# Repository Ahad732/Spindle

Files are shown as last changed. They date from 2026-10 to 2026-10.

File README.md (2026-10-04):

# Spindle

Spindle is a low-cost, custom e-reader made with the RP2350A. It consists of a 2.7 inch e-paper display, which is much better than a typical screen. It also consists of a 128Mbit flash, which is 16MiB, and 5 user buttons. The firmware for Spindle can be found [here](https://github.com/Keyaan-07/spindle-firmware/tree/main). The firmware is custom written in C. The power consumption averages at about 40mA, making it a low-power device.  

See the board on [KiCanvas](https://kicanvas.org/?repo=https%3A%2F%2Fgithub.com%2FAhad732%2FSpindle%2Ftree%2Fmain%2FHardware)  

## Features:
- Dual ARM-Cortex M-33 and Hazard3 RISC-V cores
- WiFi Functionality
- 16MiB flash
- 2.7 inch e-paper display
- 100% open-sourced
- USB High Speed compatible
- switching charging
- low-power consumption

# CAD: 
So, the CAD is made in onshape, [link here](https://cad.onshape.com/documents/20ea073a3a4d1e1a3f911dd9/w/66e638eb5b2ab30e1451aaff/e/b663f709698147c3db960dcd). We have tried our best to make it look as clean as possible.  This is what the assembly looks like:  
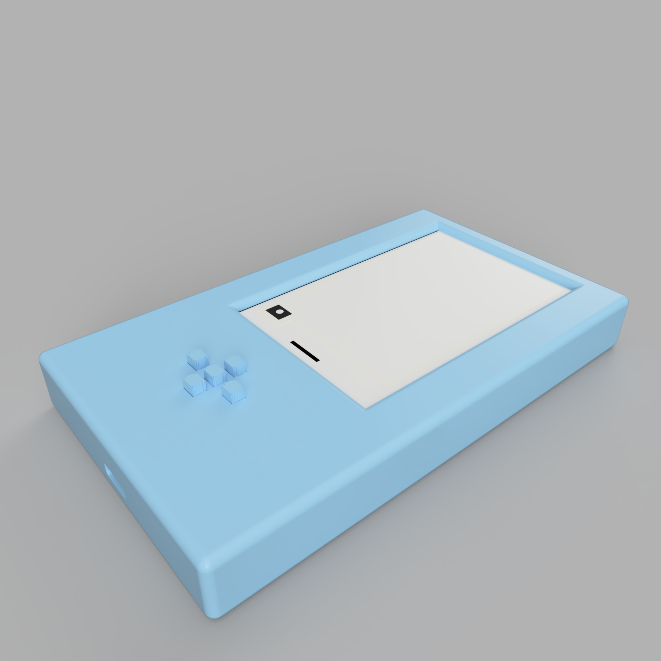
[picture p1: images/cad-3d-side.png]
cad-3d
  
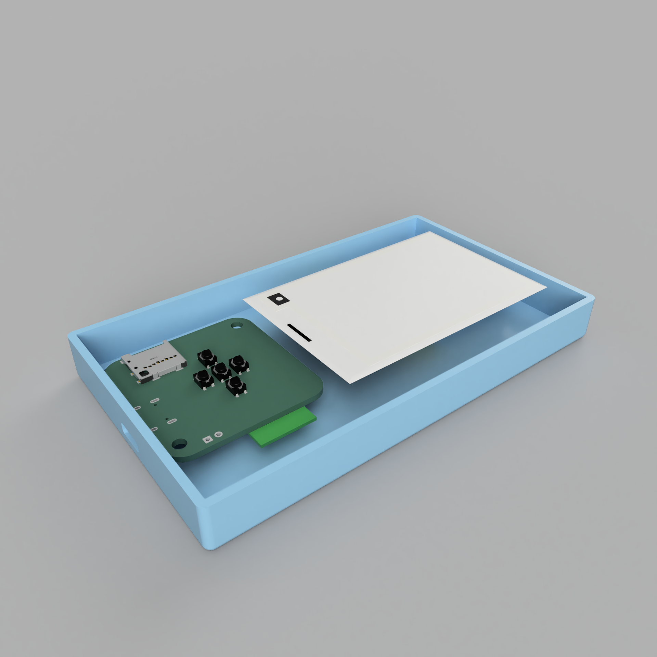
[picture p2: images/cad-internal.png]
cad-internal
  

## Images:  
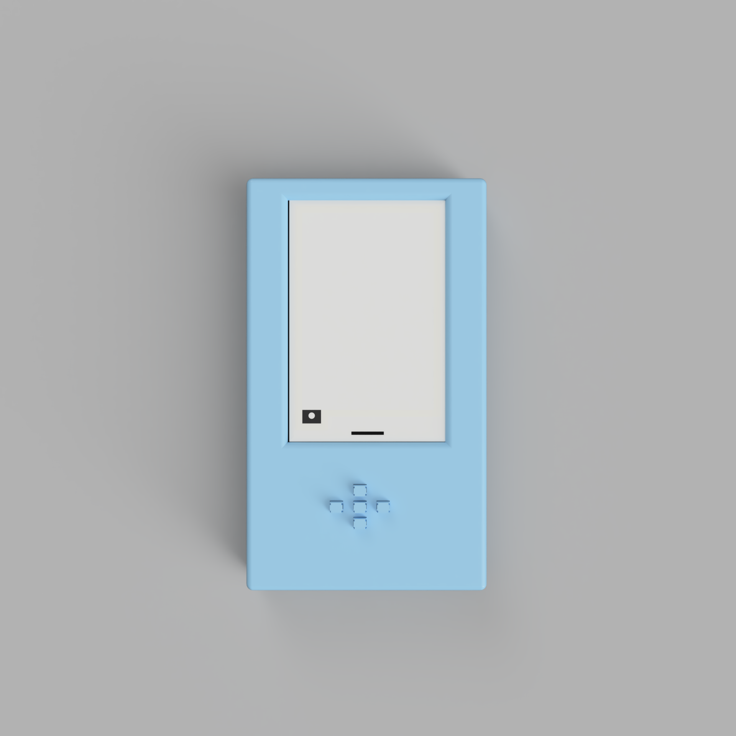
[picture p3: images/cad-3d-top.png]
3d-render

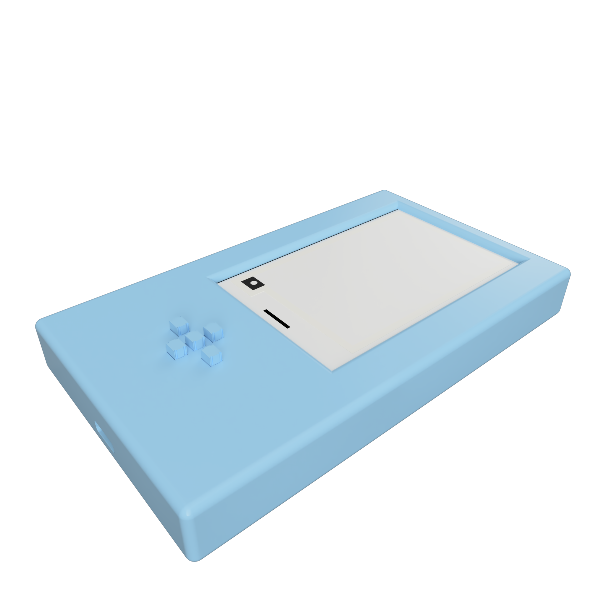
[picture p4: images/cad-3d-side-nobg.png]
3d-side
  
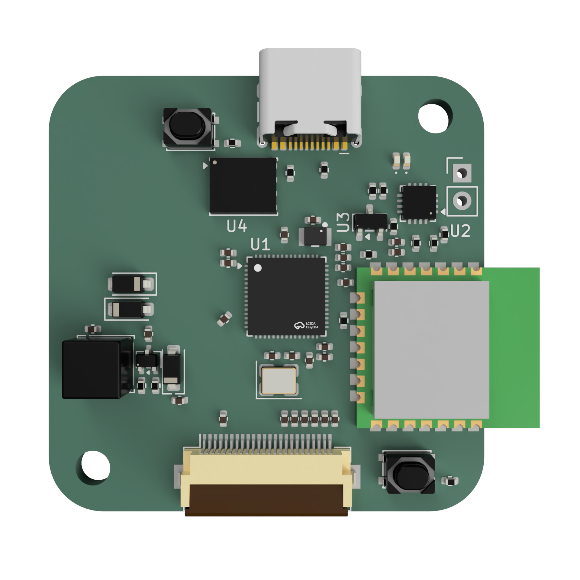
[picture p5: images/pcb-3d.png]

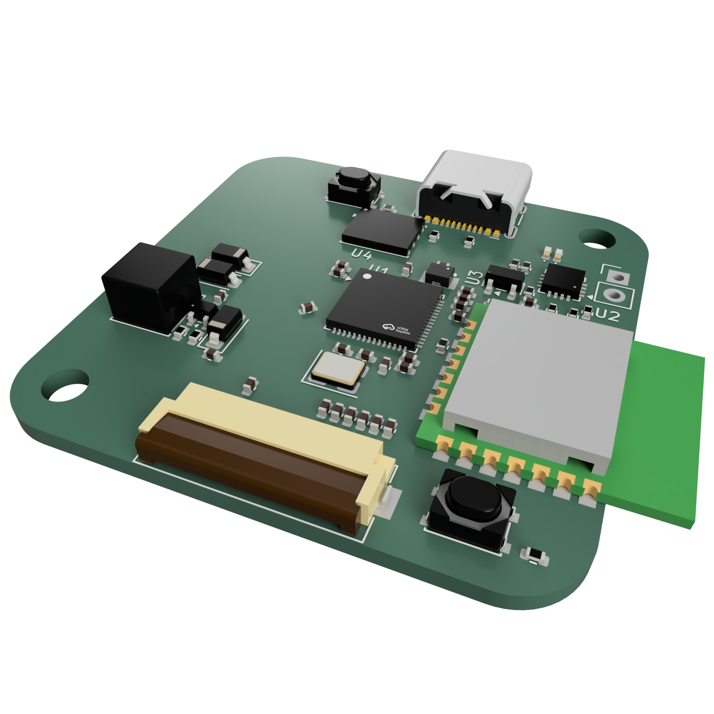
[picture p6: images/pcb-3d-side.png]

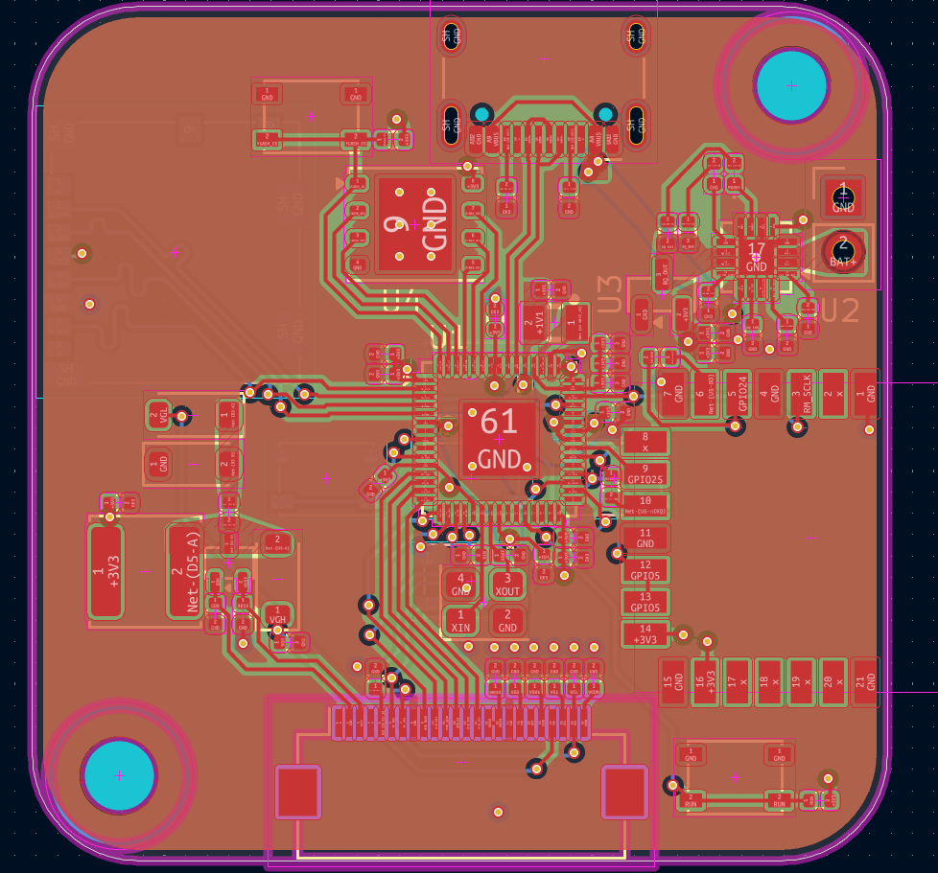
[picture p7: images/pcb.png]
pcb
  
sch  

We made this project as a fun way to learn to integrate various components and work together on different parts of the same project!  

# BOM
|Designator |Footprint |Value |Quantity |Price|Link |
|---|---|---|---|-----|---|
|C1, C2 |402 |15p |100 |0.09 |https://www.lcsc.com/product-detail/C696887.html |
|C10, C11, C12, C4, C6, C7, C8, C9 |402 |1u |100 |0.58 |https://www.lcsc.com/product-detail/C46614477.html |
|C13, C14, C15, C16, C17, C18, C19, C20, C21, C24|402 |100n |100 |0.16 |https://www.lcsc.com/product-detail/C5137487.html |
|C23, C25, C26, C27, C3, C5 |402 |4.7u |20 |0.42 |https://www.lcsc.com/product-detail/C318563.html |
|D1 |402 |GREEN |100 |0.61 |https://www.lcsc.com/product-detail/C55072283.html |
|D2 |402 |RED |100 |0.55 |https://www.lcsc.com/product-detail/C55072282.html |
|D3, D4, D5 |D_SOD-123 |MBR0530 |20 |0.74 |https://www.lcsc.com/product-detail/C5140024.html |
|J1 |USB_C_Receptacle_HCTL_HC-TYPE-C-16P-01A |USB_C_Receptacle_USB2.0_16P|20 |0.48 |https://www.lcsc.com/product-detail/C42400234.html |
|J2 |PinHeader_1x02_P2.54mm_Vertical |Conn_01x02_Pin |DNP |DNP  | |
|J3 |Hirose_FH12-24S-0.5SH_1x24-1MP_P0.50mm_Horizontal|Conn_01x24_Pin |10 |0.67 |https://www.lcsc.com/product-detail/C19273933.html |
|J4 |microSD_HC_Molex_104031-0811 |Micro_SD_Card |3 |2.5  |https://www.lcsc.com/product-detail/C585350.html |
|L1 |L_Radial_D6.0mm_P4.00mm |47u |5 |0.53 |https://www.lcsc.com/product-detail/C72618.html |
|L2 |L_Sunlord_SWPA5040S |3.3u |20 |0.77 |https://www.lcsc.com/product-detail/C5289414.html |
|Q1 |SOT-323_SC-70 |Si1308EDL |5 |0.59 |https://www.lcsc.com/product-detail/C4355112.html |
|R1 |402 |60.4K |100 |0.09 |https://www.lcsc.com/product-detail/C49653007.html |
|R10 |402 |1M |100 |0.08 |https://www.lcsc.com/product-detail/C49652954.html |
|R11, R12, R13, R14, R15, R16, R17, R2 |402 |10K |100 |0.11 |https://www.lcsc.com/product-detail/C49653007.html |
|R18 |402 |470 |100 |0.06 |https://www.lcsc.com/product-detail/C54920802.html |
|R3, R4, R7 |402 |1.5K |100 |0.06 |https://www.lcsc.com/product-detail/C54920744.html |
|R5, R6 |402 |5.1K |100 |0.06 |https://www.lcsc.com/product-detail/C54920813.html |
|R8 |402 |1K |100 |0.07 |https://www.lcsc.com/product-detail/C54920633.html |
|R9 |402 |2.2 |100 |0.07 |https://www.lcsc.com/product-detail/C54920775.html |
|SW1, SW2, SW3, SW4, SW5, SW6 |SW_SPST_PTS810 |SW_Push |10 |3.43 |https://www.lcsc.com/product-detail/C221895.html |
|U1 |QFN-60-1EP_7x7mm_P0.4mm_EP3.4x3.4mm |RP2350A |3 |3.9  |https://www.lcsc.com/product-detail/C42411118.html |
|U2 |VQFN-16-1EP_3x3mm_P0.5mm_EP1.6x1.6mm |BQ24074RGT |3 |7.59 |https://www.lcsc.com/product-detail/C54313.html |
|U3 |SOT-23 |MCP1700x-330xxTT |5 |0.59 |https://www.lcsc.com/product-detail/C41381676.html |
|U4 |WSON-8-1EP_6x5mm_P1.27mm_EP3.4x4.3mm |W25Q128JVP |3 |2.32 |https://www.lcsc.com/product-detail/C2641199.html |
|U5 |rpi_rmc20452t |rpi_rmc20452t |2 |10.33|https://www.lioncircuits.com/parts/SC1169 |
|Y1 |Crystal_SMD_3225-4Pin_3.2x2.5mm |12mhz |10 |0.55 |https://www.lcsc.com/product-detail/C16197268.html |
| | |Battery |1 |4.87 |https://robu.in/product/wly103443-1500mah-3-7v-single-cell-rechargeable-lipo-battery/|
| | |Screen |1 |14.52|https://robu.in/product/2-7-inch-black-white-e-paper-good-display-with-touch-panel/  |
| | | |PCB+Stencil+Shipping|22.35| |
| | | |Parts Shipping |8.82 | |
| | | |Total |88.56| |

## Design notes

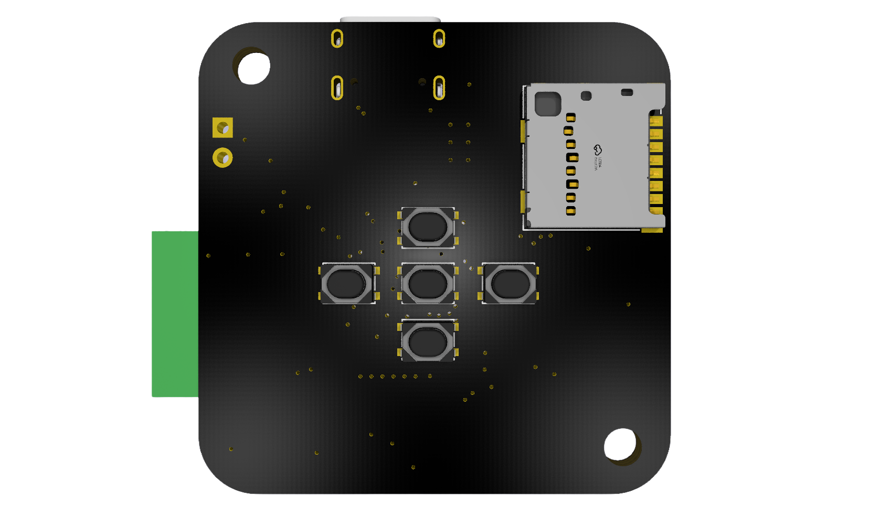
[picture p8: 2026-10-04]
images/pcb-3d-back.png

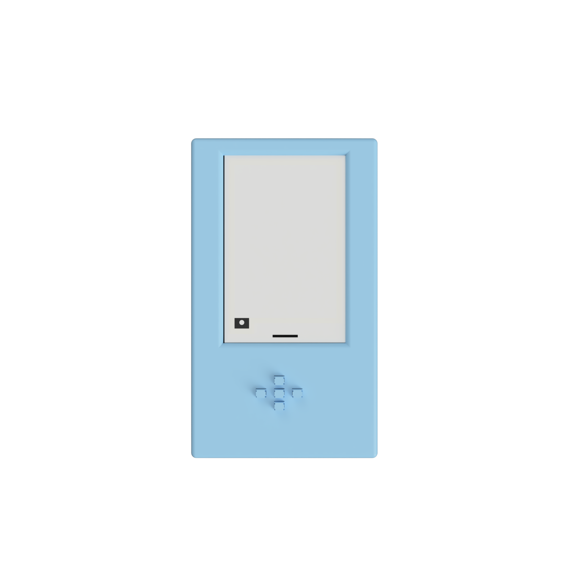
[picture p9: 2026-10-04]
images/cad-3d-top-nobg.png

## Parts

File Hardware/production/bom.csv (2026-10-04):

Designator | Footprint | Quantity | Value | LCSC Part #
C1, C2 | 0402 | 2 | 15p
C10, C11, C12, C4, C6, C7, C8, C9 | 0402 | 8 | 1u
C13, C14, C15, C16, C17, C18, C19, C20, C21, C23, C24 | 0402 | 11 | 100n
C25, C26, C27, C3, C5 | 0402 | 5 | 4.7u
D1 | 0402 | 1 | GREEN
D2 | 0402 | 1 | RED
D3, D4, D5 | D_SOD-123 | 3 | MBR0530
J1 | USB_C_Receptacle_HCTL_HC-TYPE-C-16P-01A | 1 | USB_C_Receptacle_USB2.0_16P
J2 | PinHeader_1x02_P2.54mm_Vertical | 1 | Conn_01x02_Pin
J3 | Hirose_FH12-24S-0.5SH_1x24-1MP_P0.50mm_Horizontal | 1 | Conn_01x24_Pin
J4 | microSD_HC_Molex_104031-0811 | 1 | Micro_SD_Card
L1 | L_Sunlord_SWPA5040S | 1 | 47u
L2 | IND-SMD_L2.0-W1.6_AOTA-B201610S3R3-101-T | 1 | 3.3u
Q1 | SOT-323_SC-70 | 1 | Si1308EDL
R1 | 0402 | 1 | 60.4K
R10 | 0402 | 1 | 1M
R11, R17, R19, R2 | 0402 | 4 | 10K
R18 | 0402 | 1 | 470
R3, R4, R7 | 0402 | 3 | 1.5K
R5, R6 | 0402 | 2 | 5.1K
R8 | 0402 | 1 | 1K
R9 | 0402 | 1 | 2.2R
SW1, SW2, SW3, SW4, SW5, SW6, SW7 | SW_SPST_PTS810 | 7 | SW_Push
U1 | QFN-60-1EP_7x7mm_P0.4mm_EP3.4x3.4mm | 1 | RP2350A
U2 | VQFN-16-1EP_3x3mm_P0.5mm_EP1.6x1.6mm | 1 | BQ24074RGT
U3 | SOT-23 | 1 | MCP1700x-330xxTT
U4 | WSON-8-1EP_6x5mm_P1.27mm_EP3.4x4.3mm | 1 | W25Q128JVP
U5 | rpi_rmc20452t | 1 | <value>
Y1 | Crystal_SMD_3225-4Pin_3.2x2.5mm | 1 | Crystal_GND24

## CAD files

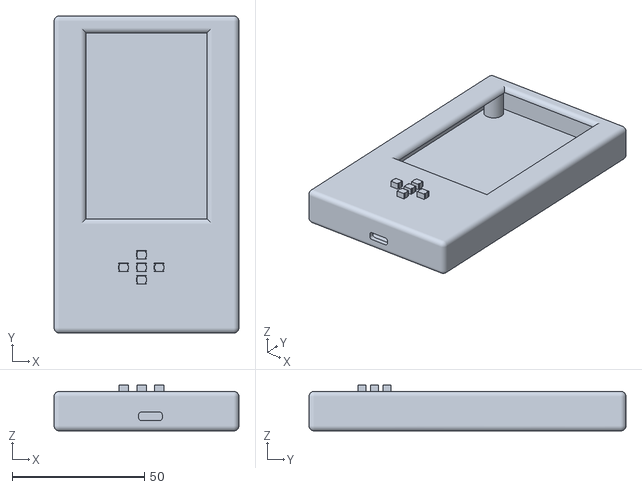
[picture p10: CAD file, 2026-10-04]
CAD/spindle-enclosure-printable.stl
70.0 x 120.0 x 17.4

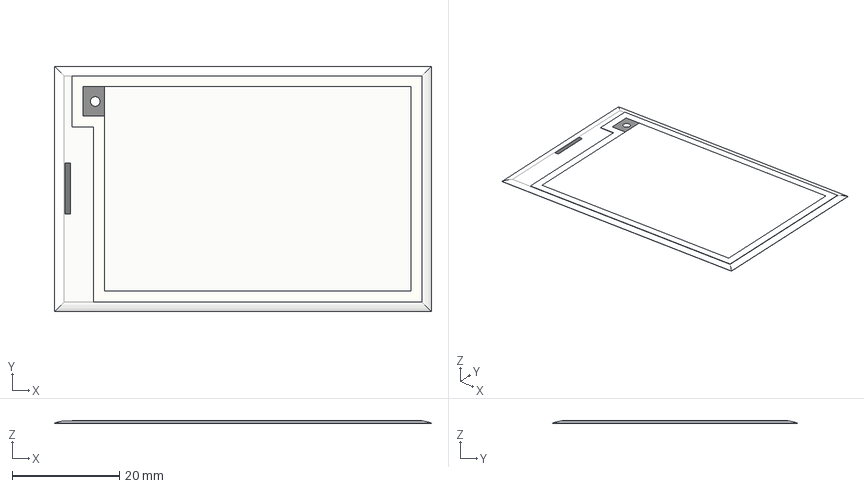
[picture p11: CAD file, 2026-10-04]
CAD/GDEY027T91-EINK.step
70.4 x 45.8 x 0.55 mm

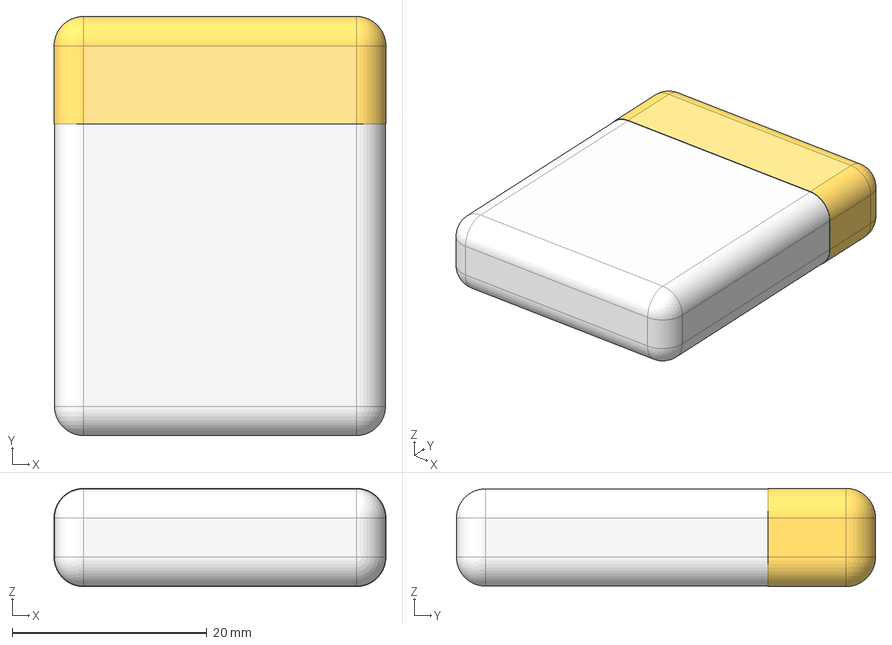
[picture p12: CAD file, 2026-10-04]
CAD/lipo-cell-103443.step
34.1 x 43.0 x 10.1 mm

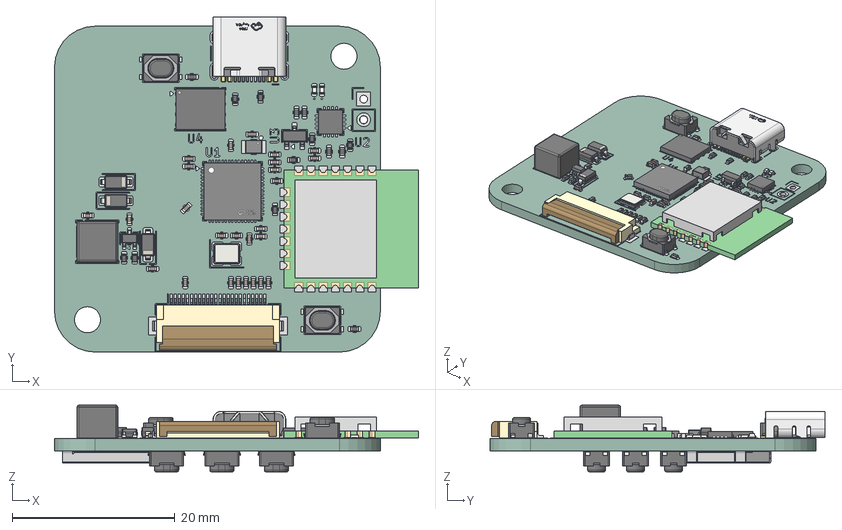
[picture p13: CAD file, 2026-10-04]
CAD/Spindle.step
44.7 x 41.1 x 8.18 mm
D_SOD-123 x 3
SOT-23
Crystal_SMD_3225-4Pin_3.2x2.5mm
C_0402_1005Metric x 26
QFN-16-1EP_3x3mm_P0.5mm_EP1.7x1.7mm
R_0402_1005Metric x 14
RPI-RM2-R3
SOT-323_SC-70
SW_SPST_PTS810 x 7
IND-SMD_L2.0-W1.6_AOTA-B201610S3R3-101-T
lock
pins
USB-C-SMD_TYPE-C16PIN
a69dfe88-8551-11ed-a139-00155d22e2d7_part
a69dffdc-8551-11ed-a139-00155d22e2d7_part
a69e005e-8551-11ed-a139-00155d22e2d7_part
QFN-60_L7.0-W7.0-P0.40-TL-EP3.4
WSON-8-1EP_6x5mm_P1.27mm_EP3.4x4.3mm
LED_0402_1005Metric x 2
SIM-SMD_8P-1040310811
Spi3EE9_pad
Spi3EE9_silkscreen x 2
Spi3EE9_PCB

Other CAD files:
CAD/spindle-assembly.step
CAD/spindle-enclosure.step

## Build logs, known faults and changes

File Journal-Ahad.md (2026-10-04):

# 20 September 2026

I started working on this project today and began by first doing some parts research and when i was going to do that my teammate called me and told to use esp32-s3 first and due to some issues we had to switch to RP2350a which is also a good choice for a e-reader. It features a e-ink display which we thought of using as it gives a better battery backup. I also arranged the schematic.



# 21 September 2026

I wired the whole schematic again as i did many parts of it wrong and this time took help of AI for the 24-pin connector of the E-Ink display as i had to make a whole boost circuit which was quite complex for me to make by myself as we will be using a bare screen.



# 23 September 2026

I have done doing most of the wiring of the power pins of the rp2350a and will be looking forware on completing the PCB and shipping this weeks hours and doin about 12 to 13 hours this week as in the last week i had exactly 10 hours and a single minute. i also assigned the remaining footprints





# 26 & 27 September 2026

I worked on the layout of the PCB which i did almost 3 times ad i messed it up so bad the first two times I did it and found out that patience was the key for a better layout so i took 45 minutes for it. I then started routing the PCB and I found out that the board was of 4 layers and i touted the whole thing AGAIN which was a pain for my mind and i also found at the last time that my teammate didnt know how to code the touch screen so I also had to add push buttons for it. I completed the BOM which took quite good amount of time and i also have decided to do cad the next week






# 1 & 2 October 2026

I started doing the CAD party of the reader which was simple which i thought would be hard as i am a complete beginer to it. I took a look at some tutorials for understanding it which was like an hour of videos.i also took a look at PCB in which i added the Raspberry pi RM 2 module for the wi-fi and bluetooth connectivity.




# 3 October 2026

So, i started the Cad work and was pleased by how easy it was to do the cad and had to continue it. Fast forward now where i m in a situation to complete the 10 hours while my teammate is lagging behind by like 5 hours :) 



[Keyaan here]
So, i did not like how the PCB had been routed, and thus i routed it myself again. The process was good!! I assigned a lot of 3d models too and got some amazing photos:  
  
  
  
  
Yeah so that is it!!

# 4 October 2026
I did most of the CAD work today, and lapsed it all along, and this is what the CAD looks like in onshape(Finally huh):  
3d cad  
cad top

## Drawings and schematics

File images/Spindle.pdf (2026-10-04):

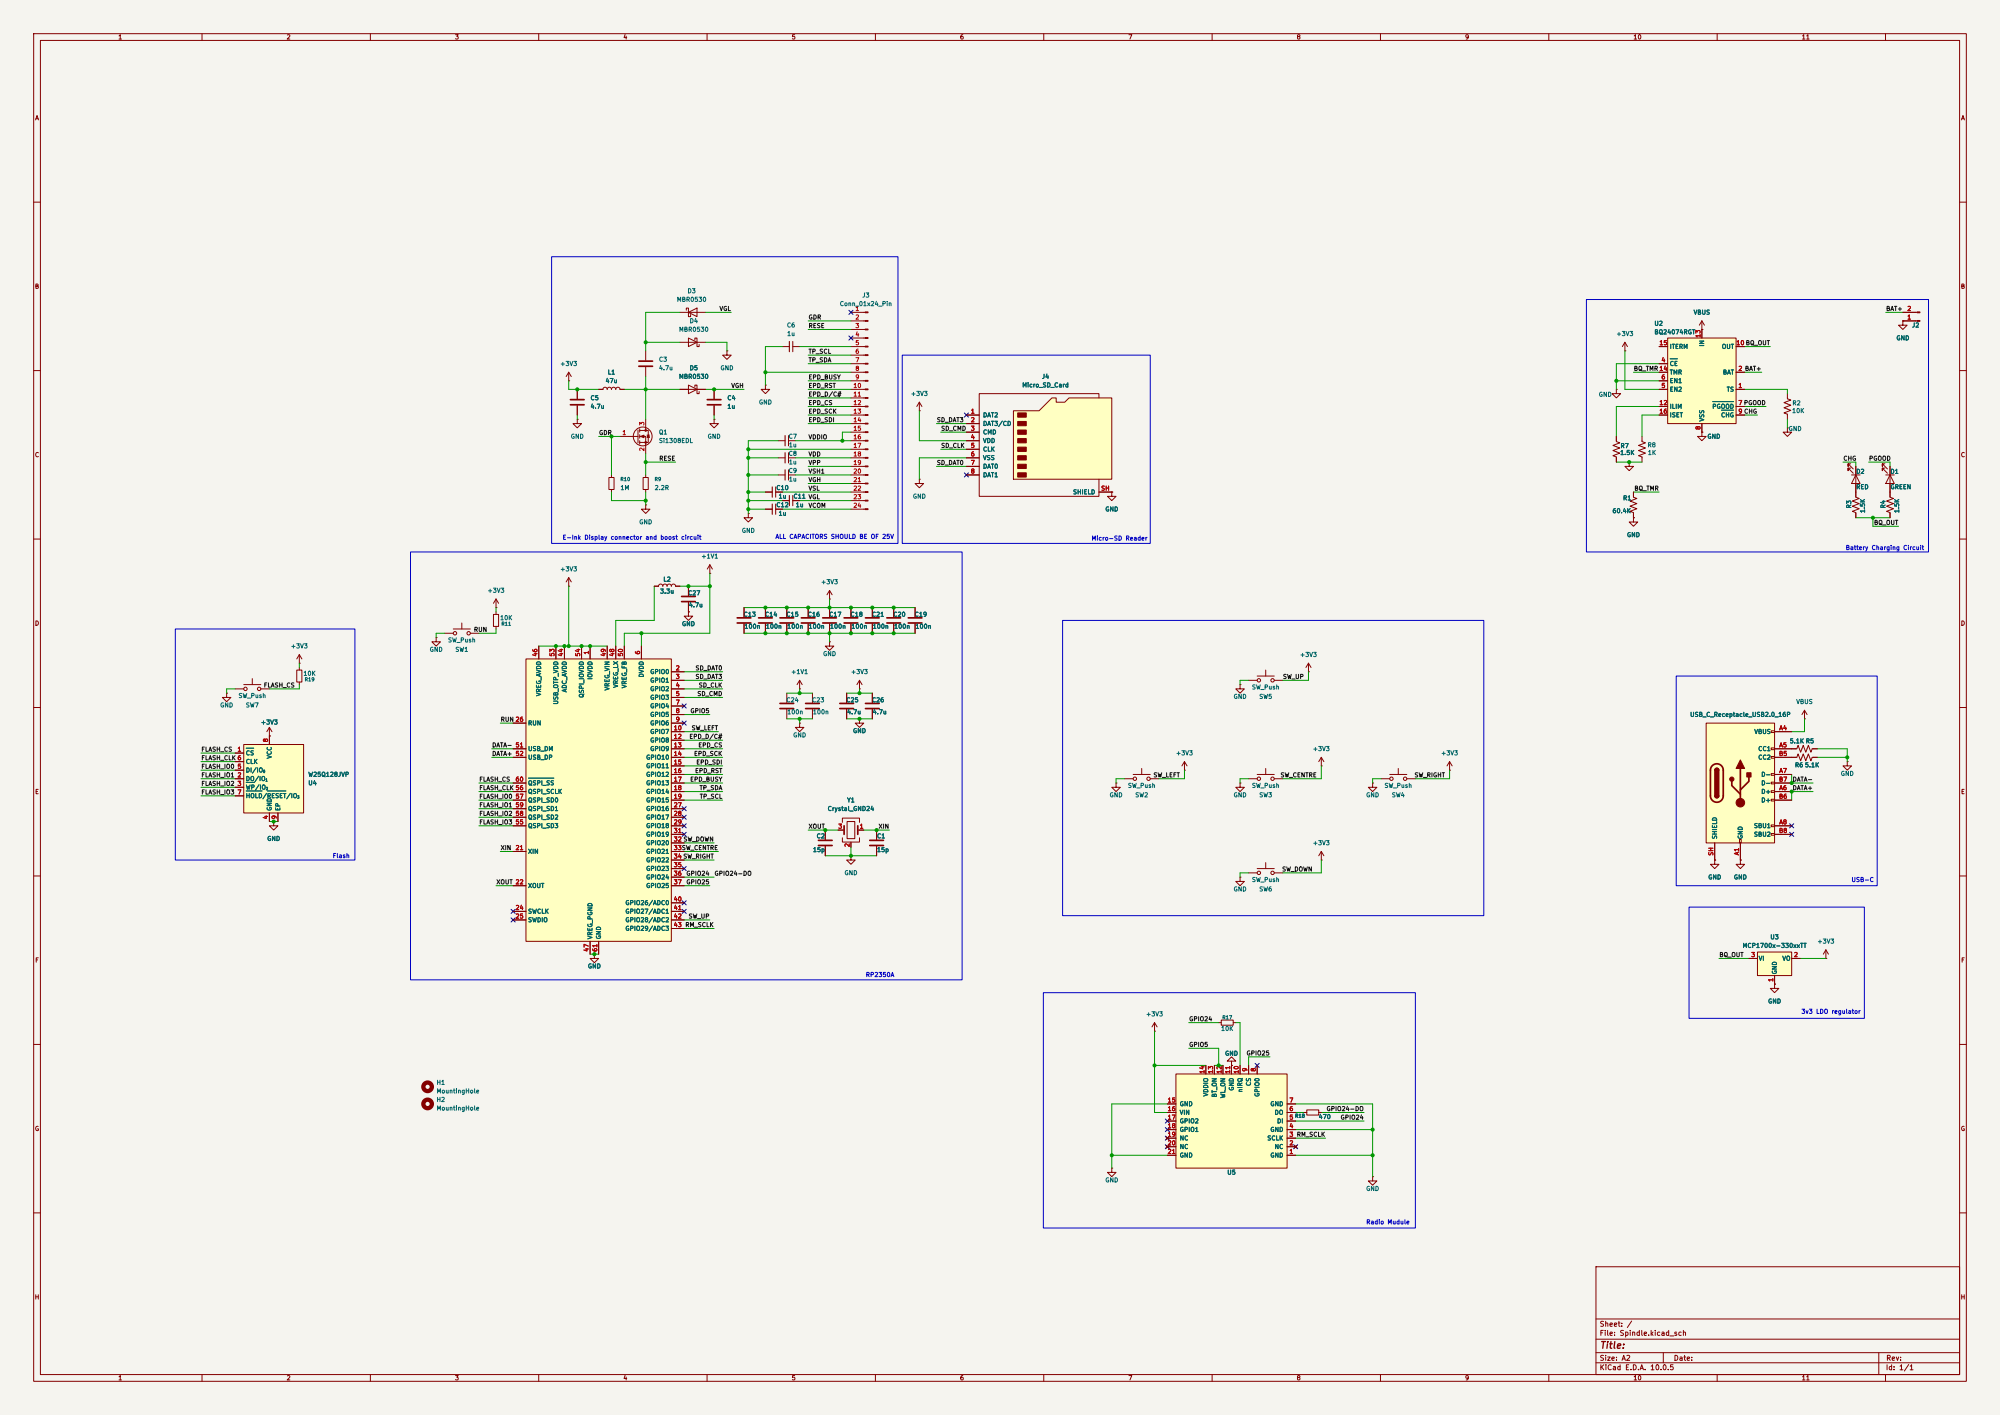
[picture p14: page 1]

SW_Push SW2 | SW5 SW_Push SW_Push SW6 | SW_Push GND SW4 | USB_C_Receptacle_USB2.0_16P +3V3 C17

4 DI/IO0 5 CLK 6 HOLD/RESET/IO3 7 VCC

3v3 LDO regulator Radio Mudule RP2350A

9 nIRQ 10 GND 11 WL_ON 12 BT_ON 13 VDDIO 14 GND 15

Size: A2 | Rev:
KiCad E.D.A. 10.0.5 | Id: 1/1

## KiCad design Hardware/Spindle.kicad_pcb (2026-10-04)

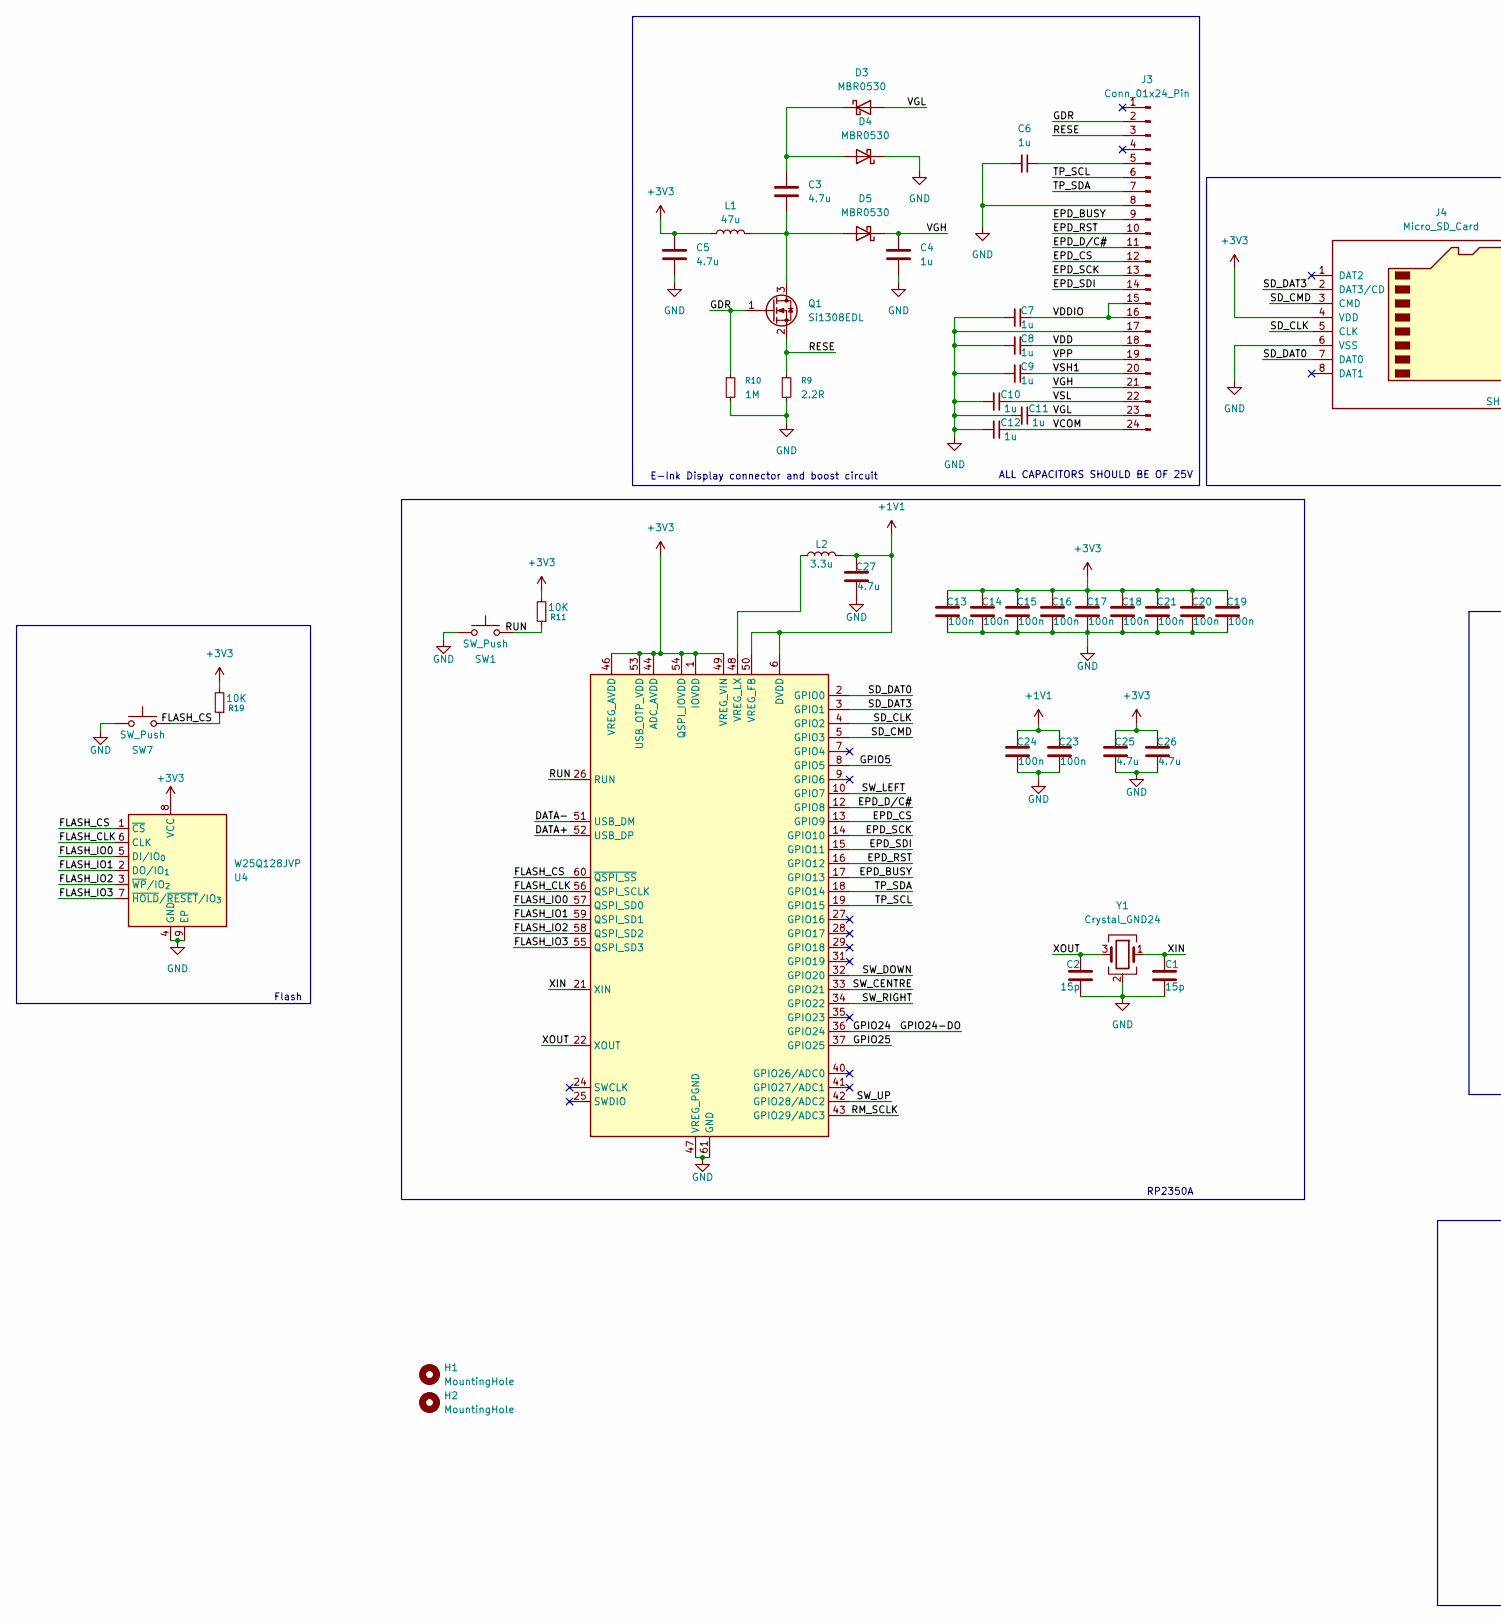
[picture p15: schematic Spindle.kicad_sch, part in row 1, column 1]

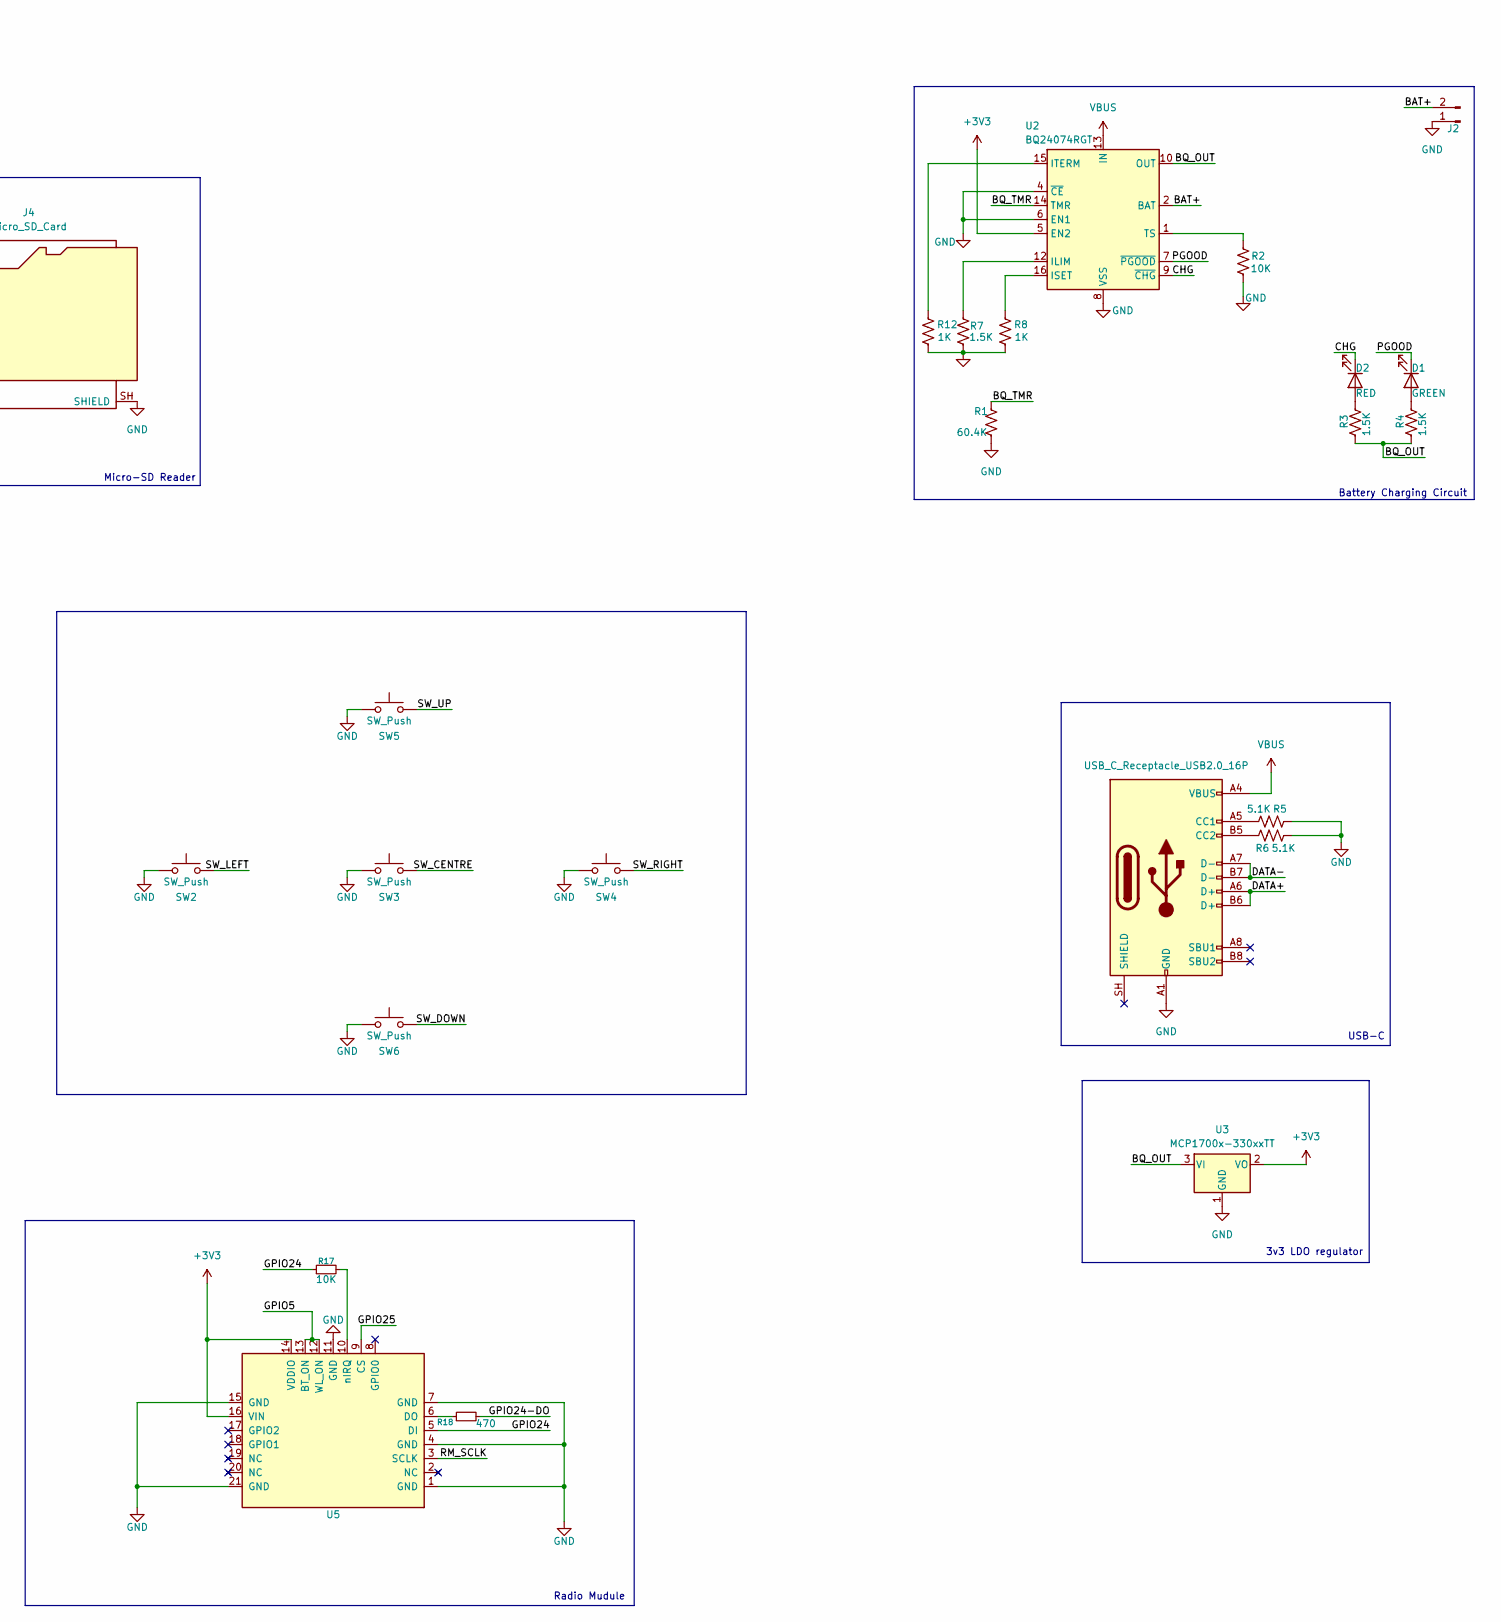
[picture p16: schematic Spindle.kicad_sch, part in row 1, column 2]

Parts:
C1, C2: 15p; C_0402_1005Metric
C3, C5, C25, C26, C27: 4.7u; C_0402_1005Metric
C4, C6, C7, C8, C9, C10, C11, C12: 1u; C_0402_1005Metric
C13, C14, C15, C16, C17, C18, C19, C20, C21, C23, C24: 100n; C_0402_1005Metric
D1: GREEN; LED_0402_1005Metric
D2: RED; LED_0402_1005Metric
D3, D4, D5: MBR0530; D_SOD-123
H1, H2: MountingHole; MountingHole_3.2mm_M3
J1: USB_C_Receptacle_USB2.0_16P; USB_C_Receptacle_HCTL_HC-TYPE-C-16P-01A
J2: Conn_01x02_Pin; PinHeader_1x02_P2.54mm_Vertical
J3: Conn_01x24_Pin; Hirose_FH12-24S-0.5SH_1x24-1MP_P0.50mm_Horizontal
J4: Micro_SD_Card; microSD_HC_Molex_104031-0811
L1: 47u; L_Sunlord_SWPA5040S
L2: 3.3u; IND-SMD_L2.0-W1.6_AOTA-B201610S3R3-101-T
Q1: Si1308EDL; SOT-323_SC-70
R1: 60.4K; R_0402_1005Metric
R2, R11, R17, R19: 10K; R_0402_1005Metric
R3, R4, R7: 1.5K; R_0402_1005Metric
R5, R6: 5.1K; R_0402_1005Metric
R8, R12: 1K; R_0402_1005Metric
R9: 2.2R; R_0402_1005Metric
R10: 1M; R_0402_1005Metric
R18: 470; R_0402_1005Metric
SW1, SW2, SW3, SW4, SW5, SW6, SW7: SW_Push; SW_SPST_PTS810
U1: RP2350A; QFN-60-1EP_7x7mm_P0.4mm_EP3.4x3.4mm
U2: BQ24074RGT; VQFN-16-1EP_3x3mm_P0.5mm_EP1.6x1.6mm
U3: MCP1700x-330xxTT; SOT-23
U4: W25Q128JVP; WSON-8-1EP_6x5mm_P1.27mm_EP3.4x4.3mm
U5: <value>; rpi_rmc20452t
Y1: Crystal_GND24; Crystal_SMD_3225-4Pin_3.2x2.5mm

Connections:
+1V1: C23.1, C24.1, C27.1, L2.2, U1.6 (DVDD), U1.23 (DVDD), U1.39 (DVDD), U1.50 (VREG_FB)
+3V3: C5.1, C13.1, C14.1, C15.1, C16.1, C17.1, C18.1, C19.1, C20.1, C21.1, C25.1, C26.1, J4.4 (VDD), L1.1, R11.2, R19.2, U1.1 (IOVDD), U1.11 (IOVDD), U1.20 (IOVDD), U1.30 (IOVDD), U1.38 (IOVDD), U1.44 (ADC_AVDD), U1.45 (IOVDD), U1.46 (VREG_AVDD), U1.49 (VREG_VIN), U1.53 (USB_OTP_VDD), U1.54 (QSPI_IOVDD), U2.5 (EN2), U3.2 (VO), U4.8 (VCC), U5.14 (VDDIO), U5.16 (VIN)
/BAT+: J2.2, U2.2 (BAT), U2.3 (BAT)
/BQ_OUT: R3.2, R4.2, U2.10 (OUT), U2.11 (OUT), U3.3 (VI)
/BQ_TMR: R1.1, U2.14 (TMR)
/CHG: D2.1 (K), U2.9 (~CHG)
/DATA+: J1.A6 (D+), J1.B6 (D+), U1.52 (USB_DP)
/DATA-: J1.A7 (D-), J1.B7 (D-), U1.51 (USB_DM)
/EPD_BUSY: J3.9, U1.17 (GPIO13)
/EPD_CS: J3.12, U1.13 (GPIO9)
/EPD_D/C#: J3.11, U1.12 (GPIO8)
/EPD_RST: J3.10, U1.16 (GPIO12)
/EPD_SCK: J3.13, U1.14 (GPIO10)
/EPD_SDI: J3.14, U1.15 (GPIO11)
/FLASH_CLK: U1.56 (QSPI_SCLK), U4.6 (CLK)
/FLASH_CS: R19.1, SW7.2, U1.60 (~QSPI_SS), U4.1 (~CS)
/FLASH_IO0: U1.57 (QSPI_SD0), U4.5 (DI/IO_{0})
/FLASH_IO1: U1.59 (QSPI_SD1), U4.2 (DO/IO_{1})
/FLASH_IO2: U1.58 (QSPI_SD2), U4.3 (~WP/IO_{2})
/FLASH_IO3: U1.55 (QSPI_SD3), U4.7 (~HOLD/~RESET/IO_{3})
/GDR: J3.2, Q1.1 (G), R10.1
/GPIO5: U1.8 (GPIO5), U5.12 (WL_ON), U5.13 (BT_ON)
/GPIO24: R17.1, R18.2, U1.36 (GPIO24), U5.5 (DI)
/GPIO25: U1.37 (GPIO25), U5.9 (CS)
/PGOOD: D1.1 (K), U2.7 (~PGOOD)
/RESE: J3.3, Q1.2 (S), R9.1
/RM_SCLK: U1.43 (GPIO29/ADC3), U5.3 (SCLK)
/RUN: R11.1, SW1.2, U1.26 (RUN)
/SD_CLK: J4.5 (CLK), U1.4 (GPIO2)
/SD_CMD: J4.3 (CMD), U1.5 (GPIO3)
/SD_DAT0: J4.7 (DAT0), U1.2 (GPIO0)
/SD_DAT3: J4.2 (DAT3/CD), U1.3 (GPIO1)
/SW_CENTRE: SW3.2, U1.33 (GPIO21)
/SW_DOWN: SW6.2, U1.32 (GPIO20)
/SW_LEFT: SW2.2, U1.10 (GPIO7)
/SW_RIGHT: SW4.2, U1.34 (GPIO22)
/SW_UP: SW5.2, U1.42 (GPIO28/ADC2)
/TP_SCL: J3.6, U1.19 (GPIO15)
/TP_SDA: J3.7, U1.18 (GPIO14)
/VCOM: C12.1, J3.24
/VDD: C8.1, J3.18
/VDDIO: C7.1, J3.15, J3.16
/VGH: C4.1, D5.1 (K), J3.21
/VGL: C11.1, D3.2 (A), J3.23
/VPP: J3.19
/VSH1: C9.1, J3.20
/VSL: C10.1, J3.22
/XIN: C1.2, U1.21 (XIN), Y1.1
/XOUT: C2.1, U1.22 (XOUT), Y1.3
GND: C1.1, C2.2, C4.2, C5.2, C6.2, C7.2, C8.2, C9.2, C10.2, C11.2, C12.2, C13.2, C14.2, C15.2, C16.2, C17.2, C18.2, C19.2, C20.2, C21.2, C23.2, C24.2, C25.2, C26.2, C27.2, D4.1 (K), J1.A1 (GND), J1.A12 (GND), J1.B1 (GND), J1.B12 (GND), J2.1, J3.8, J3.17, J4.6 (VSS), J4.SH (SHIELD), R1.2, R2.1, R5.2, R6.1, R7.1, R8.2, R9.2, R10.2, R12.2, SW1.1, SW2.1, SW3.1, SW4.1, SW5.1, SW6.1, SW7.1, U1.47 (VREG_PGND), U1.61 (GND), U2.4 (~CE), U2.6 (EN1), U2.8 (VSS), U2.17 (VSS), U3.1 (GND), U4.4 (GND), U4.9 (EP), U5.1 (GND), U5.4 (GND), U5.7 (GND), U5.11 (GND), U5.15 (GND), U5.21 (GND), Y1.2 (G), Y1.4 (G)
unnamed: D1.2 (A), R4.1
unnamed: D2.2 (A), R3.1
unnamed: C3.1, D3.1 (K), D4.2 (A)
unnamed: C3.2, D5.2 (A), L1.2, Q1.3 (D)
unnamed: J1.A5 (CC1), R5.1
unnamed: J1.B5 (CC2), R6.2
unnamed: C6.1, J3.5
unnamed: R12.1, U2.15 (ITERM)
unnamed: L2.1, U1.48 (VREG_LX)
unnamed: R7.2, U2.12 (ILIM)
unnamed: R8.1, U2.16 (ISET)
unnamed: R2.2, U2.1 (TS)
unnamed: R18.1, U5.6 (DO)
unnamed: R17.2, U5.10 (nIRQ)
VBUS: J1.A4 (VBUS), J1.A9 (VBUS), J1.B4 (VBUS), J1.B9 (VBUS), U2.13 (IN)

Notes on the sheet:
Battery Charging Circuit
E-Ink Display connector and boost circuit
Radio Mudule
Flash
Micro-SD Reader
RP2350A
3v3 LDO regulator
USB-C
ALL CAPACITORS SHOULD BE OF 25V

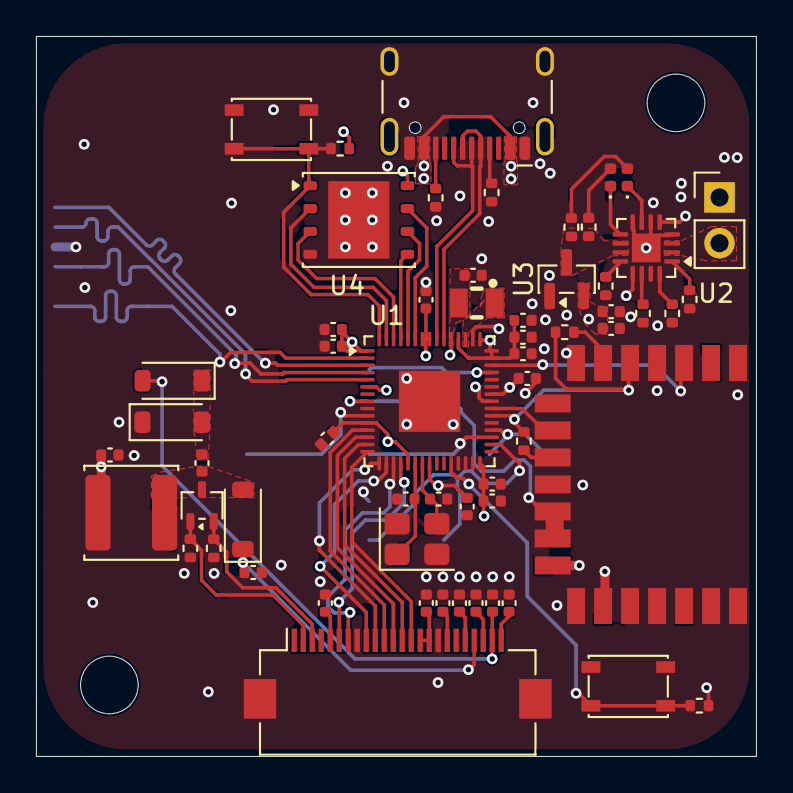
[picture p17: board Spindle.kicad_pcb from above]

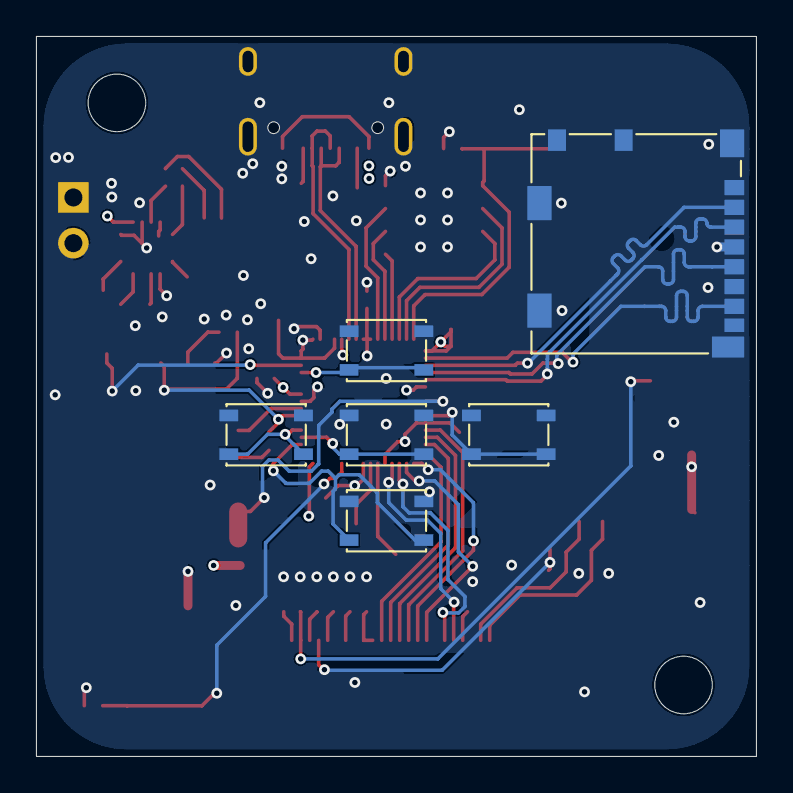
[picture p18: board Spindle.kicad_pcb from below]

Board: 4 copper layers, 40.0 x 40.0 mm, 67 parts (6 on the bottom side), 63 nets.

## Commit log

2026-09-20 updated schematic
    [Spindle.kicad_pcb, Spindle.kicad_sch]
2026-09-22 worked on the schematic
    [Spindle.kicad_sch]
2026-09-23 Started PCB layout
    [Spindle.kicad_pcb, Spindle.kicad_sch]
2026-09-24 updated PCB
    [Spindle.kicad_pcb, Spindle.kicad_sch]
2026-09-27 Completed PCB
    [Spindle.kicad_pcb, Spindle.kicad_sch, bom.csv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]
2026-09-27 Added BOM
    [BOM.csv, Spindle.step]
2026-10-03 idk what
    [BOM.csv]
2026-10-03 Updated CAD
    [Spindle.kicad_pcb, Spindle.kicad_sch, Spindle.step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]
2026-10-03 added new BOM
    [BOM.csv]
2026-10-03 better routing
    [Spindle.kicad_pcb, Spindle.kicad_sch, bom.csv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]
2026-10-03 new updatess
    [Spindle.kicad_pcb]
2026-10-04 did CAD
    [Spindle.kicad_pcb, Spindle.kicad_sch, Spindle.step]
2026-10-04 added CAD files
    [GDEY027T91-EINK.step, lipo-cell-103443.step, spindle-assembly.step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]
2026-10-04 latest production files
    [Spindle.kicad_pcb, positions.csv]
2026-10-04 idk why
    [Spindle.kicad_pcb]
